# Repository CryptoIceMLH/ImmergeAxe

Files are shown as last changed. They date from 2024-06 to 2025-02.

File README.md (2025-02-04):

# **ImmergeAxe**

## **A <a href="https://bitaxe.org/" target="_blank">Bitaxe</a> Series Immersion System Accessory**

### What's in this Repo

- [x] 3D print STLs

- [x] Arduino Code

- [x] BOM

- [x] Wiring Diagram

- [x] All up to date
#

**Buy me a coffee**

If you wish to support my work you can donate with BTC: 

⚡ BTC LN : cryptoice@walletofsatoshi.com

⚡ BTC Onchain: 347ePgUhyvztUWVZ4YZBmBLgTn8hxUFNeQ

Bitaxe_Immersion_System

























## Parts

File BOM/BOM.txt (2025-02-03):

Immerge Axe parts !! 

Sit down this is going to be a long one.. 

lets break this down into some structure : 

Tank : 
Tank in made of Perspex Clear Sheet
1 x Main tube is 76.2mm x 76.2mm / 3.2mm thich /200mm tall  square tube ( main tank ) 
1 x 76mm x 76mm / 3mm thick Perspex Clear Sheet   (rear floor plate to be welded on ) 
1 x 70mm x 70mm / 3mm thick Perspex Clear Sheet   (hot liquid bafle plate to be welded on ) 
All Cut Type: Straight with polished ends as you will need to glue ( weld ) tank together.
I got my parts from plastock.co.uk

You will also need some Plastic Weld i got this : 
https://www.amazon.co.uk/gp/product/B00QQNNWIW/ref=ppx_yo_dt_b_search_asin_title?ie=UTF8&psc=1
and to apply it 
https://www.amazon.co.uk/gp/product/B099N39JY4/ref=ppx_yo_dt_b_search_asin_title?ie=UTF8&psc=1
https://www.amazon.co.uk/gp/product/B0BBB197Z2/ref=ppx_yo_dt_b_search_asin_title?ie=UTF8&psc=1
1x 80mm fan 
https://www.aliexpress.com/item/32263003396.html?spm=a2g0o.order_list.order_list_main.217.6f751802DgME4e
1x80mm radiator 
https://www.aliexpress.com/item/32846114986.html?spm=a2g0o.order_list.order_list_main.140.6f751802DgME4e
1x coolant pump 
https://www.aliexpress.com/item/4000628329697.html?spm=a2g0o.order_list.order_list_main.182.6f751802DgME4e
4x spring screws for bitaxe heatsink 
https://www.aliexpress.com/item/1005001679743964.html?spm=a2g0o.order_list.order_list_main.170.6f751802DgME4e
a few feet of tubing for the plumbing 
https://www.aliexpress.com/item/4000574988258.html?spm=a2g0o.order_list.order_list_main.165.6f751802DgME4e
4x Barb fittings ( 2 for tank , 2 for pump )
https://www.aliexpress.com/item/1005005513782034.html?spm=a2g0o.order_list.order_list_main.150.6f751802DgME4e
1x end cap for pump 
https://www.aliexpress.com/item/1005002539184457.html?spm=a2g0o.order_list.order_list_main.144.6f751802DgME4e
extra heatsinks for your bitaxe pcb 
https://www.aliexpress.com/item/32849625854.html?spm=a2g0o.order_list.order_list_main.135.6f751802DgME4e
2x toggle switches ( 1 for pump on off , 1 for LED on off ) 
https://www.aliexpress.com/item/1005005989323670.html?spm=a2g0o.order_list.order_list_main.130.6f751802DgME4e
1x POtentiometer / resistor for PUMP PWM control 100k
https://www.aliexpress.com/item/1005007303099321.html?spm=a2g0o.order_list.order_list_main.125.6f751802DgME4e
1 x 12v DC supply jack socket ( watch out what size you get to marry to your psu pin ) 
https://www.aliexpress.com/item/1005002401496504.html?spm=a2g0o.order_list.order_list_main.110.6f751802DgME4e
2x 80mm grils for your fan and rad 
https://www.aliexpress.com/item/32866623989.html?spm=a2g0o.order_list.order_list_main.95.6f751802DgME4e
1x 12v to 5v buck converter for mining supply
https://www.aliexpress.com/item/1005005737177802.html?spm=a2g0o.order_list.order_list_main.212.6f751802DgME4e
1x 12v to 5v buck converter for all other functions 
https://www.aliexpress.com/item/1005006711605548.html?spm=a2g0o.order_list.order_list_main.160.6f751802DgME4e
1x pair of Deans connector for wiring harners at Tank lid join
https://www.aliexpress.com/item/1005006363245473.html?spm=a2g0o.order_list.order_list_main.155.6f751802DgME4e
1x spool of 26AWG wire in RED , BLACK , YELLOW, BLUE 
https://www.aliexpress.com/item/1005004167126040.html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
1x spool of 22AWG wire in RED , BLACK , YELLOW, BLUE 
https://www.aliexpress.com/item/1005004167126040.html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
8x same as bitaxe mounting screw for the electrical box and cable holder
1x Arduino nano
https://www.aliexpress.com/item/1005007094357913.html?spm=a2g0o.order_list.order_list_main.149.469f1802cDCVHb
1x pair of female and male 6 pin JST connector for data wire harness in tank 
https://www.aliexpress.com/item/1005005501257848.html?

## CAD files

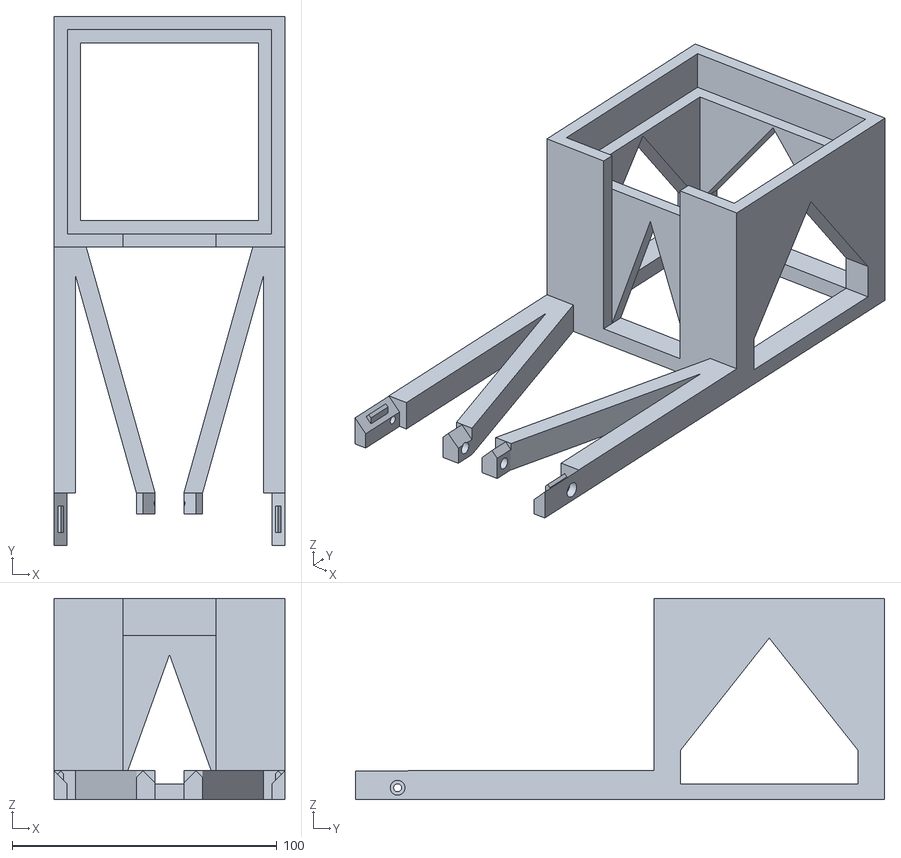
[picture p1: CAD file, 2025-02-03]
3D print STLs/V2Current/Main Frame v2 SPLIT - PT1- (1)-cryptocloaks.com.obj
87.0 x 199.7 x 76.0

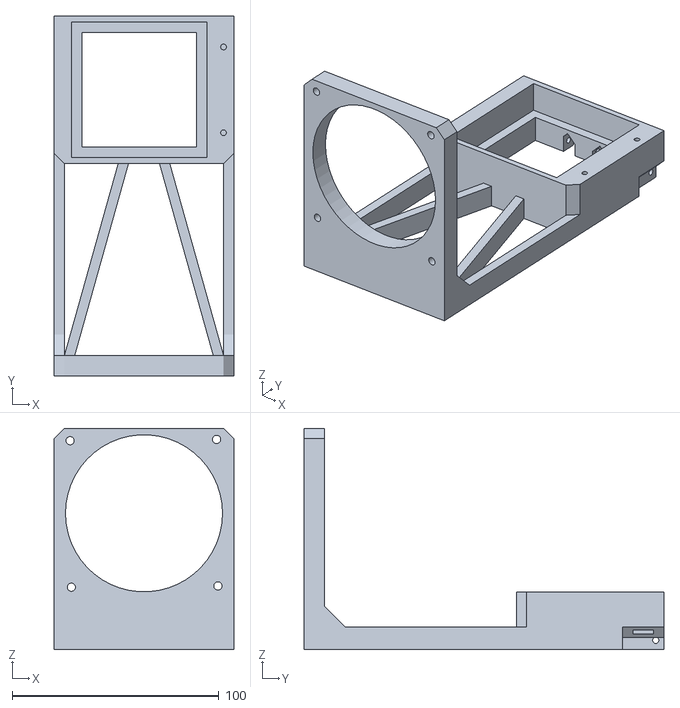
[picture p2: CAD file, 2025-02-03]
3D print STLs/V2Current/Main Frame v2 SPLIT - PT1- (2)-cryptocloaks.com.obj
87.0 x 174.3 x 107.1

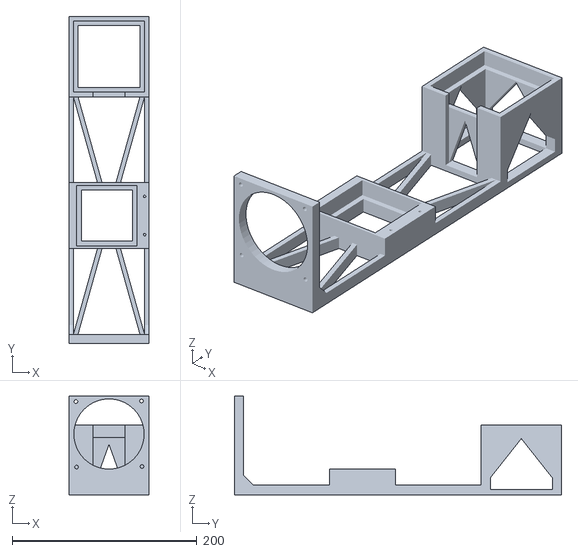
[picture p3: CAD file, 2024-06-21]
3D print STLs/V2Current/main frame signlepart-MLH.stl
87.0 x 354.0 x 107.1

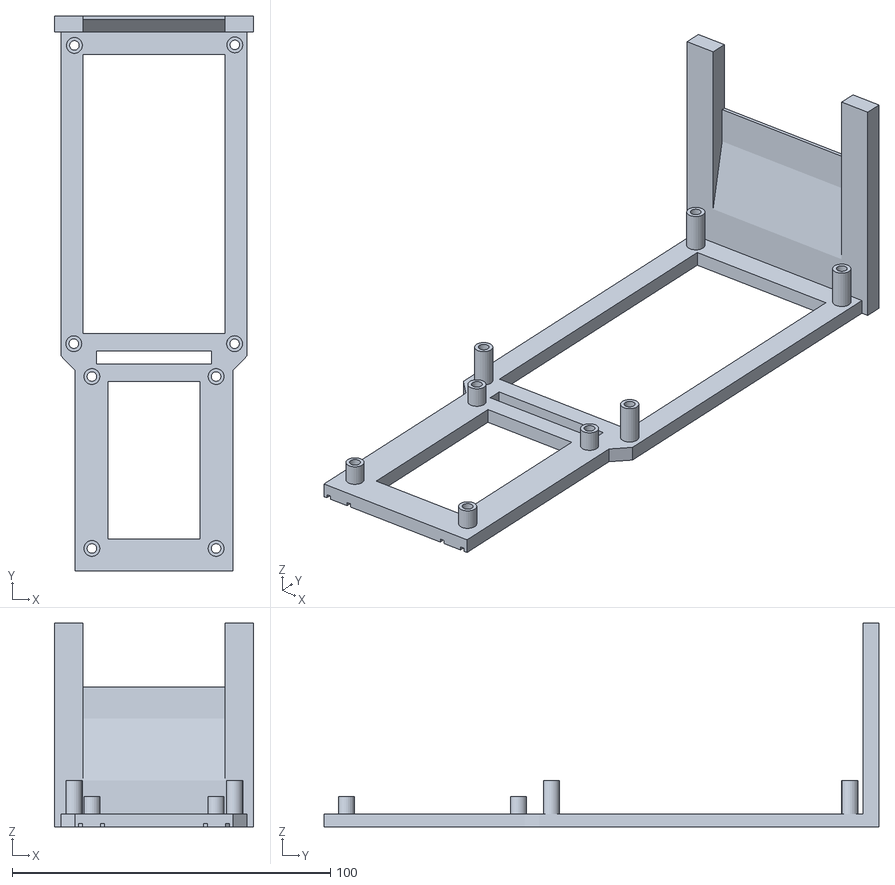
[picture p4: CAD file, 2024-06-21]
3D print STLs/V1/Bitaxe and buck frame.stl
62.5 x 174.2 x 64.0

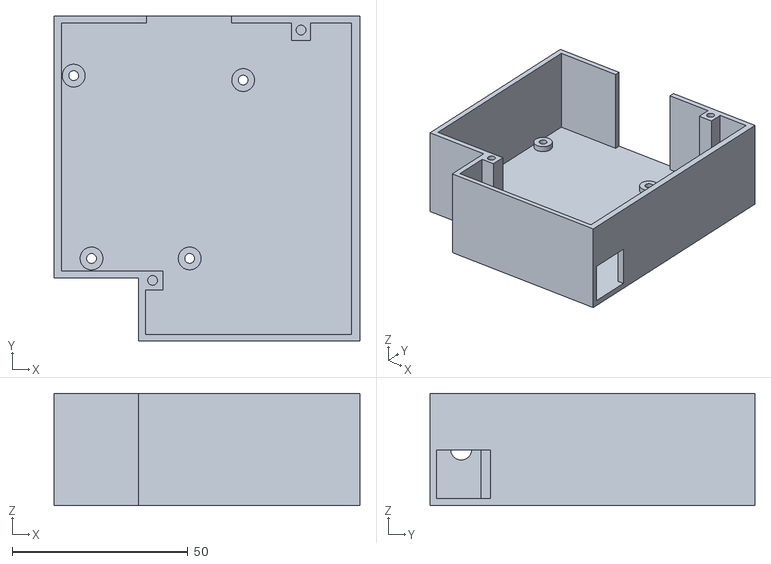
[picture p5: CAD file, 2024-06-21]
3D print STLs/V1/controller box.stl
87.0 x 92.6 x 32.0

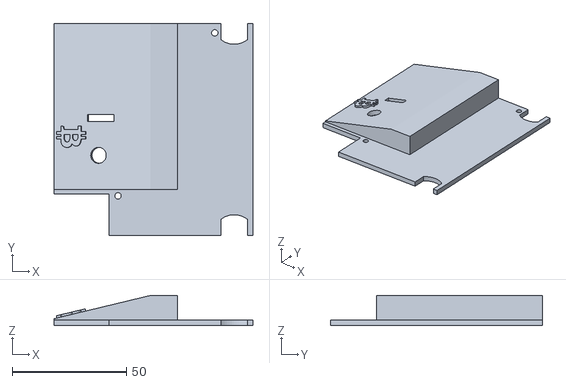
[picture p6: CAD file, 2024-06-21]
3D print STLs/V1/controller box lid.stl
87.0 x 92.6 x 13.2

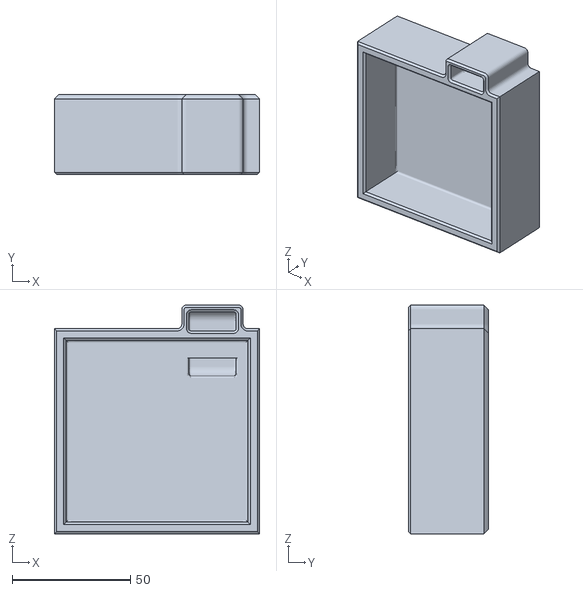
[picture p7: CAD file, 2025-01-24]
3D print STLs/V2Current/TankLid_new-gobrrr.me.stl
87.0 x 34.0 x 97.0

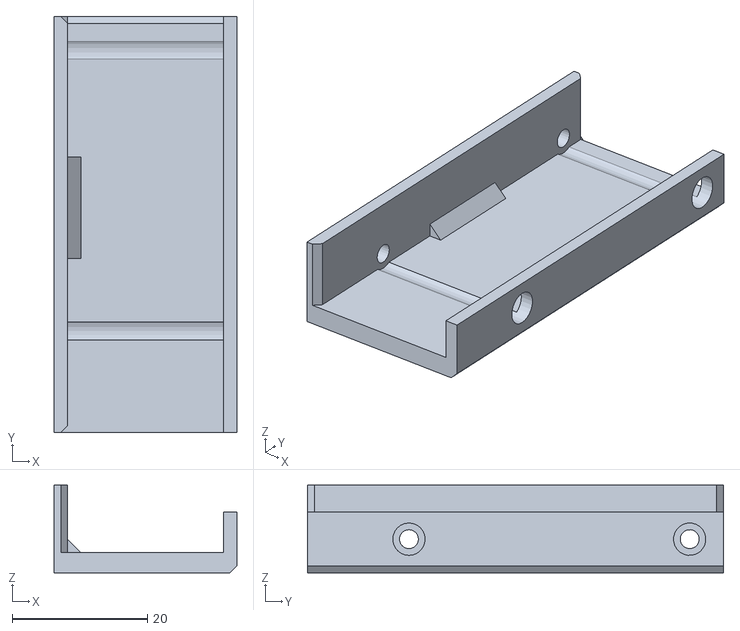
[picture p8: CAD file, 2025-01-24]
3D print STLs/V2Current/Rear cable management-gobrrr.me.stl
27.0 x 61.5 x 13.0

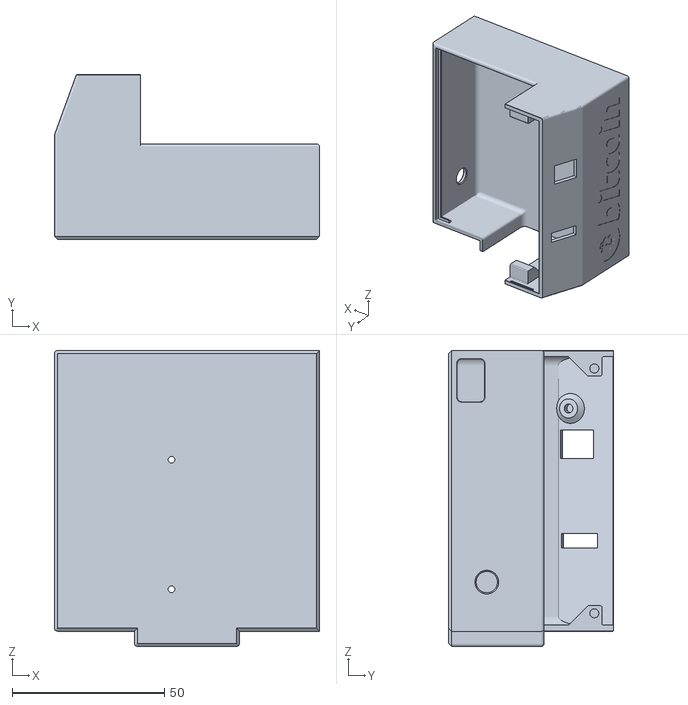
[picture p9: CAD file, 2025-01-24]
3D print STLs/V2Current/ImmergeAxe_Box_V2-gobrrr.me.stl
87.0 x 54.1 x 97.1

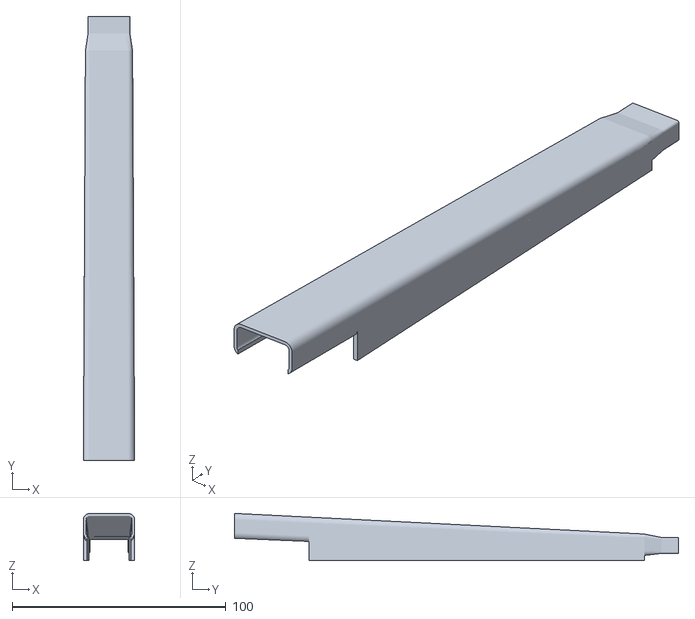
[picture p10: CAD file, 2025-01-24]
3D print STLs/V2Current/CableTube-gobrrr.me.stl
24.0 x 207.6 x 22.0

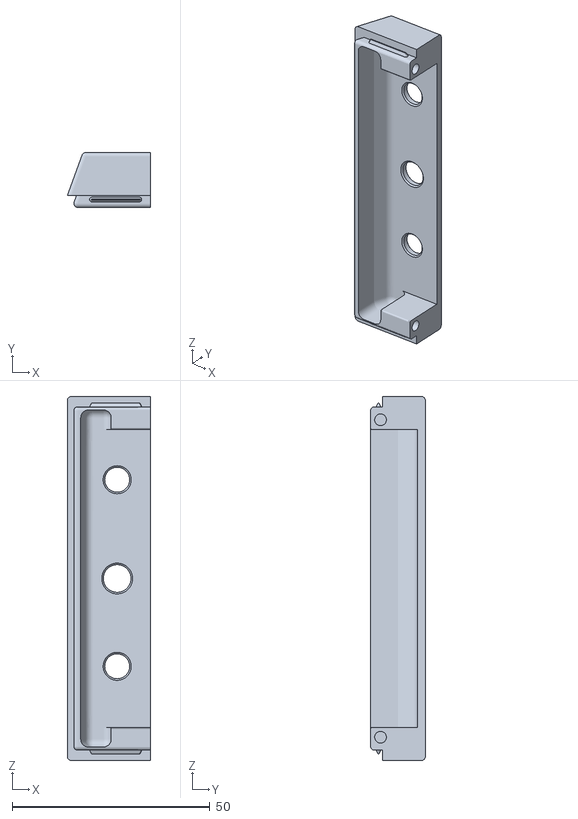
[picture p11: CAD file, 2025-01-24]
3D print STLs/V2Current/Box_Lid_V2-gobrrr.me.stl
21.1 x 13.9 x 92.1

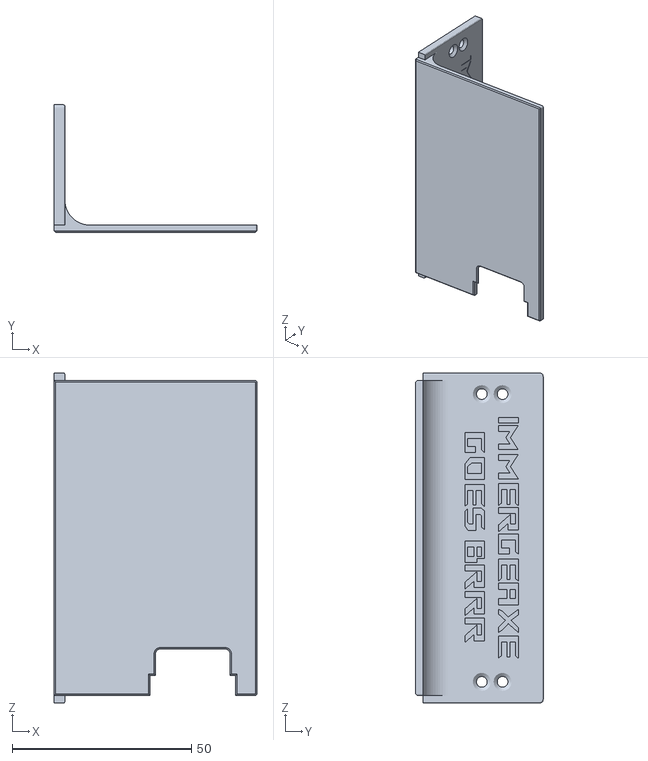
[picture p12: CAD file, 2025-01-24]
3D print STLs/V2Current/Box_Backcover_V2.1-gobrrr.me.stl
56.6 x 35.6 x 92.1

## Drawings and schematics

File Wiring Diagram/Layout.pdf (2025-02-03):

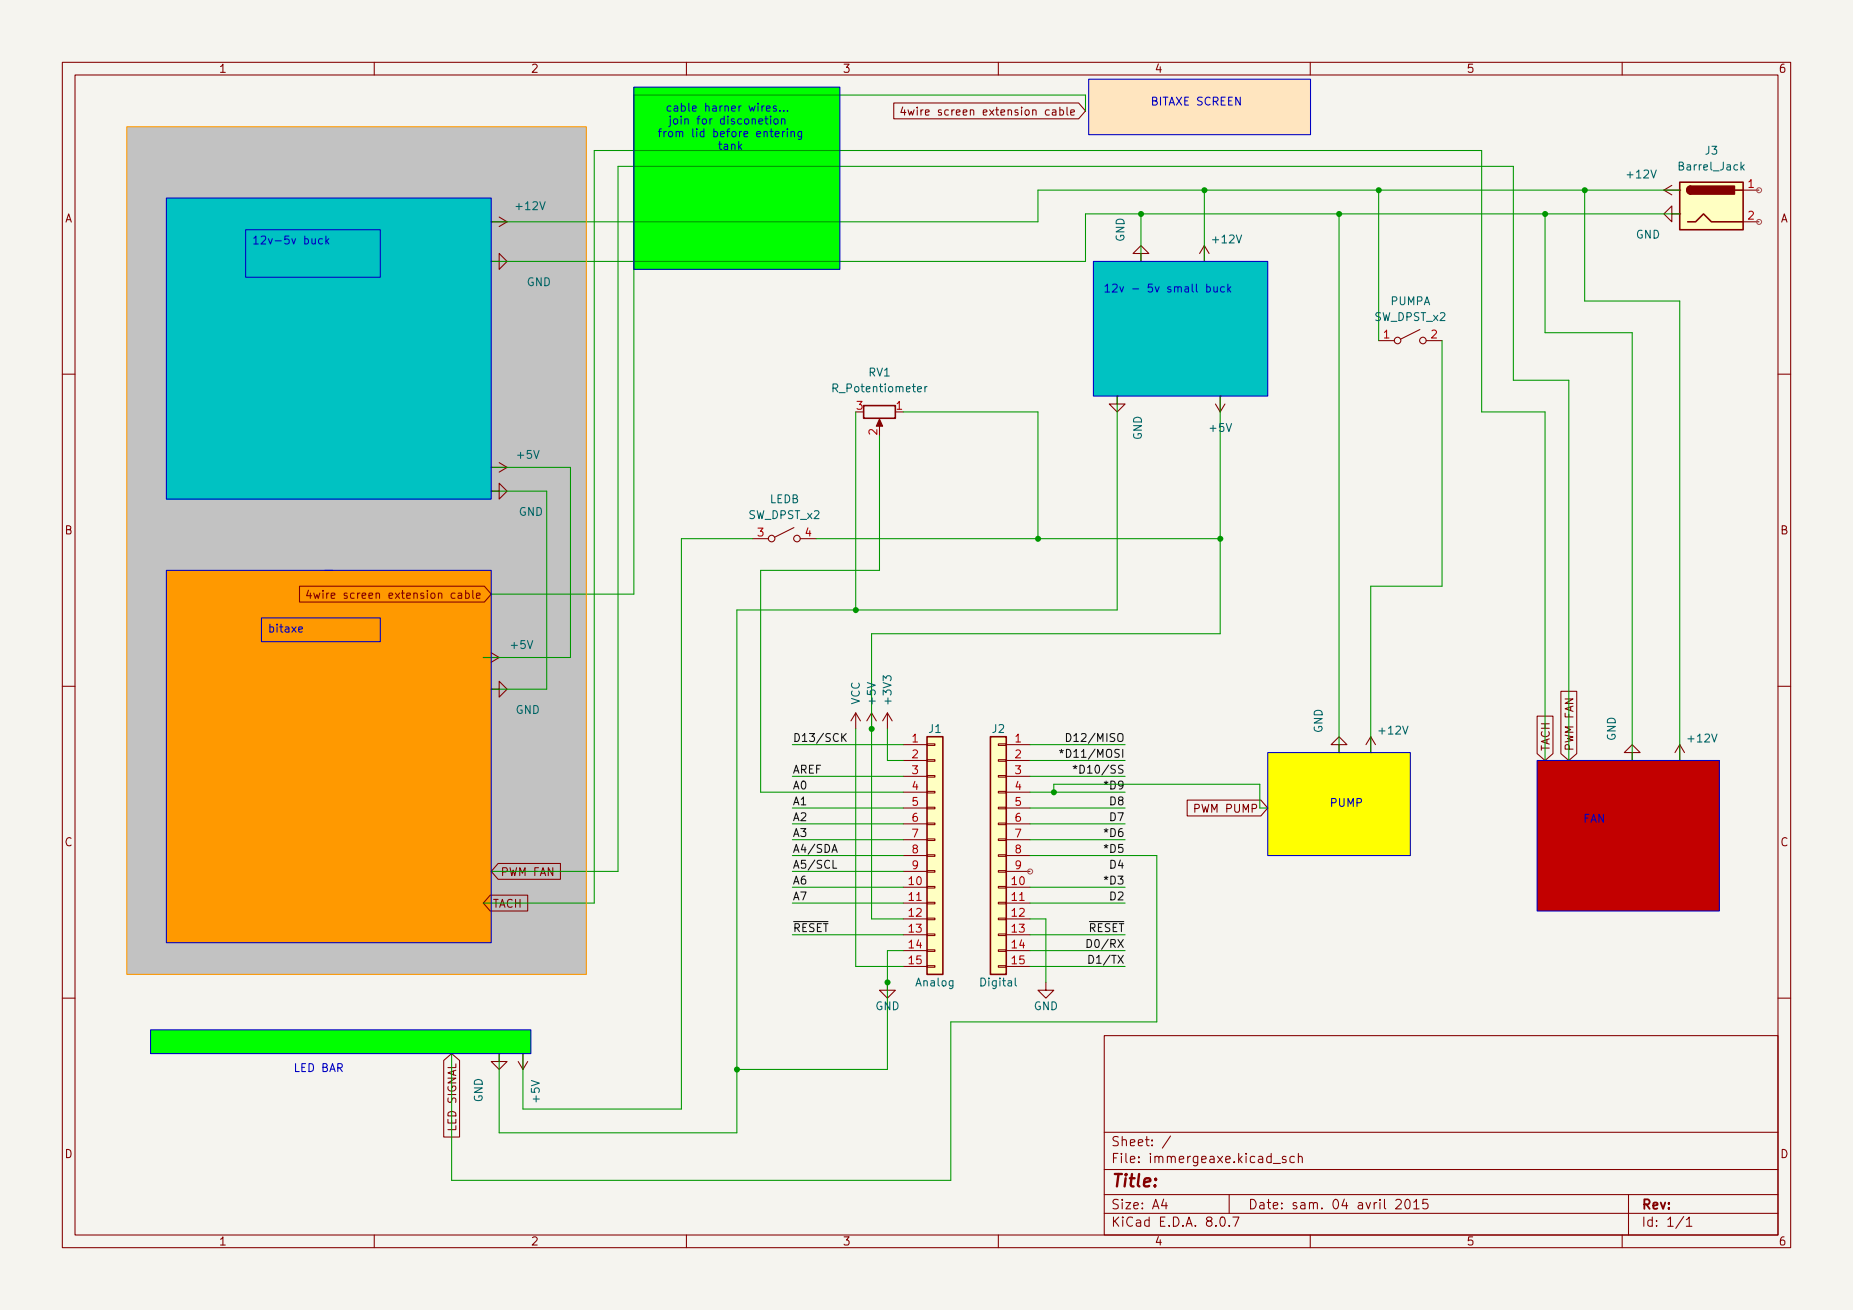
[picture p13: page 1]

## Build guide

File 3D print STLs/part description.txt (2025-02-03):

main frame.stl - as the name suggests, this is the main all in one frame that holds all the parts together. 

controller box.stl - box that houses all electronics , cabling, controls

controller box lid.stl - the lid to the electronics box that also holds the pumps speed knob, (v2 also has a LED on / off switch ) and bitaxe display.

Bitaxe and buck frame.stl - frame to mount bitaxe 200 series and 12V -> 5V(adjusted) Buck converter

Main split frame extra parts : 2x - M3 Threaded heat inserts  & 2x - M3 35mm

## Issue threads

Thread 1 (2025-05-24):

On the BOM.txt

P-A-Trick, 2025-05-24:
On the BOM.txt what measurements are the screws and fittings, also the tubes and so on... some links are outdated, it would be better to get a part list with measurements and I did not find any construction information....

thanks

best regards
Patrick

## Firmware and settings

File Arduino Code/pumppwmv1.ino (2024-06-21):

const int ledPin = 9;  //pin 9 has PWM funtion
const int potPin = A0; //pin A0 to read analog input

//Variables:
int value = 0; //save analog value

void setup(){
  //Input or output?
  Serial.begin(9600);
  pinMode(ledPin, OUTPUT); 
  pinMode(potPin, INPUT); //Optional 
  }

void loop(){
  value = analogRead(potPin);          //Read and save analog value from potentiometer
  value = map(value, 0, 1023, 0, 255); //Map value 0-1023 to 0-255 (PWM)
  analogWrite(ledPin, value);          //Send PWM value to led
  Serial.println(value);
 }
 

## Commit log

2024-06-21 Create controller box lid.stl
    [controller box lid.stl]
2024-06-21 Create controller box.stl
    [controller box.stl]
2024-06-21 Create main frame.stl
    [main frame.stl]
2024-06-21 Create Bitaxe and buck frame.stl
    [Bitaxe and buck frame.stl]
2025-01-24 Create Rear cable management.stl
    [Rear cable management.stl]
2025-02-03 Create main frame signlepart-MLH.stl
    [main frame signlepart-MLH.stl]
2025-02-03 Create Main Frame v2 SPLIT - PT1- (2)-cryptocloaks.com.obj
    [Main Frame v2 SPLIT - PT1- (2)-cryptocloaks.com.obj]
2025-02-03 Create Rear cable management-gobrrr.me.stl
    [Rear cable management-gobrrr.me.stl]
2025-02-03 Create Main Frame v2 SPLIT - PT1- (1)-cryptocloaks.com.obj
    [Main Frame v2 SPLIT - PT1- (1)-cryptocloaks.com.obj]
